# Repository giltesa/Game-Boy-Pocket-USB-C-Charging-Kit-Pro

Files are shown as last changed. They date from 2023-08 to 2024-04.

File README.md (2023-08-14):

# Game Boy Pocket USB-C Charging Kit PRO

The **Game Boy Pocket USB-C Charging Kit PRO** is the new circuit for **Nintendo Game Boy Pocket**. This time is all in one circuit and includes not only the **charging controller** but also a **boost converter** and **audio amplifier**.

The modern **IPS displays** with background light require more energy than the stock display. Also, **the flash cards** to load tons of games consume the battery very fast. If you really want to enjoy the games, the best way to do it is using a rechargeable battery instead of AA batteries.

However, that is not enough because a higher consume is forcing the original electronic to strive more than it can. That may cause noise in the speaker or headphones.

Typical solution has been adding a charging circuit for the battery and a power converter to replace the old and not efficiently one which is included in the GBP. Some people also add an audio amplifier to hear better the speaker sound. All these things make the GBP perfect, however the installation require a lot of cables and can not be easy for some people without enough knowledge.

Typical installation of the 3 modules:

GBC
*(Thanks Sascha for the photo of his GB **COLOR** installation!)*

For resolving that, this new **Game Boy Pocket USB-C Charging Kit PRO** includes the three circuits in one, everything wired each other, and you will just need to solder a few points to the GBP board.

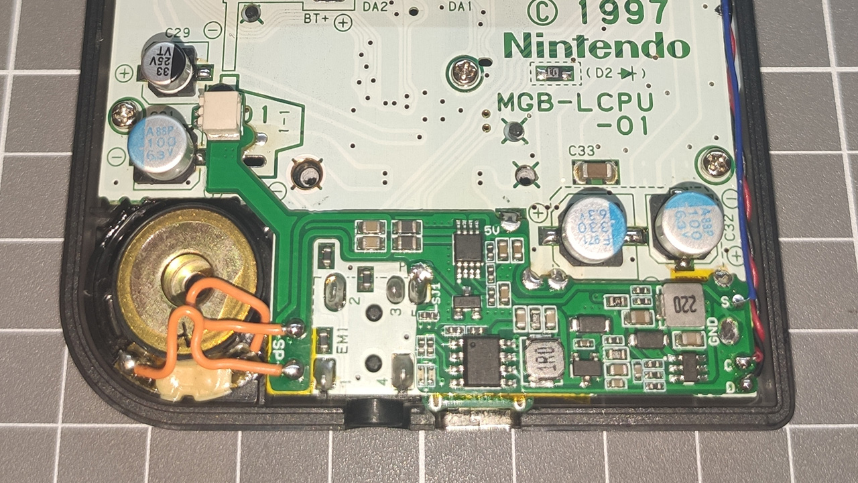
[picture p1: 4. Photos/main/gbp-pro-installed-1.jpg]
GBP


## FEATURES

-   Exact shape for Game Boy Pocket.
-   Li-Ion battery charger by USB-C with protection for charging level and overdischarge.
-   DC to DC converter (only 5V output, not compatible with the original display).
-   Audio amplifier for the speaker with a potentiometer called VR1 to setup the maximum volume.
-   Integrated LED indicators on the main board, next to the USB for charging battery (red) and full battery (green). It can be disabled by the jumper SJ1.
-   External LED indicators board for playing (white), charging battery (red) and full battery (green). Optional installation.

## Would you like it?

https://shop.giltesa.com/product/game-boy-pocket-usb-c-charging-kit-pro/

## More

- [giltesa.com](https://giltesa.com "giltesa.com")
- [twitter.com](https://twitter.com/giltesa "twitter.com")

## License

This project is licensed under a **Creative Commons** license:
**[Attribution-NonCommercial-ShareAlike 4.0 International (CC BY-NC-SA 4.0) ](https://creativecommons.org/licenses/by-nc-sa/4.0/)**

Check the [LICENSE.md](LICENSE.md) for more information.

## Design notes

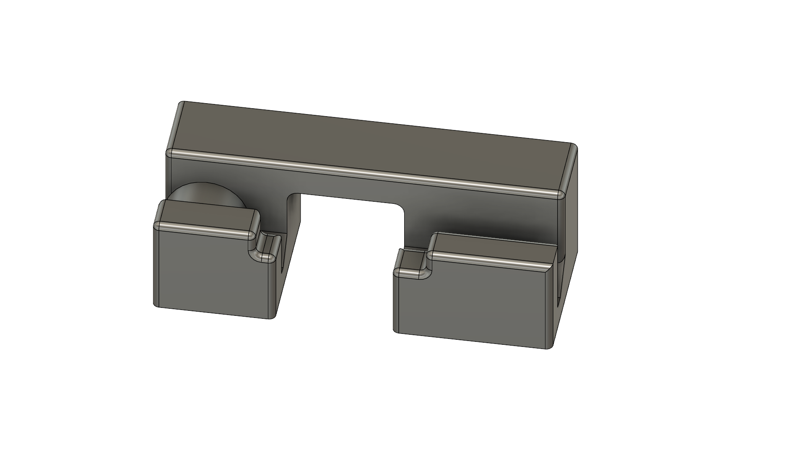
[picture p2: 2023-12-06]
2. Renders, 3D models/Cutting Tool/GBP - Cutting Tool v15.png

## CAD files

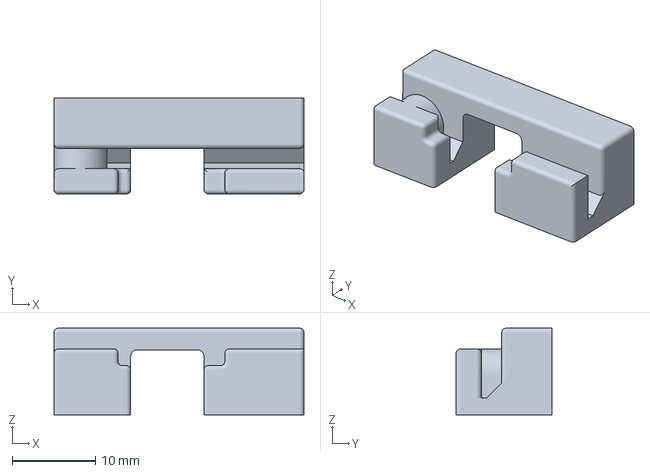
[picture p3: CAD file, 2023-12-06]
2. Renders, 3D models/Cutting Tool/GBP - Cutting Tool v15.3mf
30.0 x 11.5 x 10.4 mm

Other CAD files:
2. Renders, 3D models/Cutting Tool/GBP - Cutting Tool v15.f3d
2. Renders, 3D models/Cutting Tool/GBP - Cutting Tool v15.stl
2. Renders, 3D models/GBP USB-C Charging Kit Pro v3.1.skp

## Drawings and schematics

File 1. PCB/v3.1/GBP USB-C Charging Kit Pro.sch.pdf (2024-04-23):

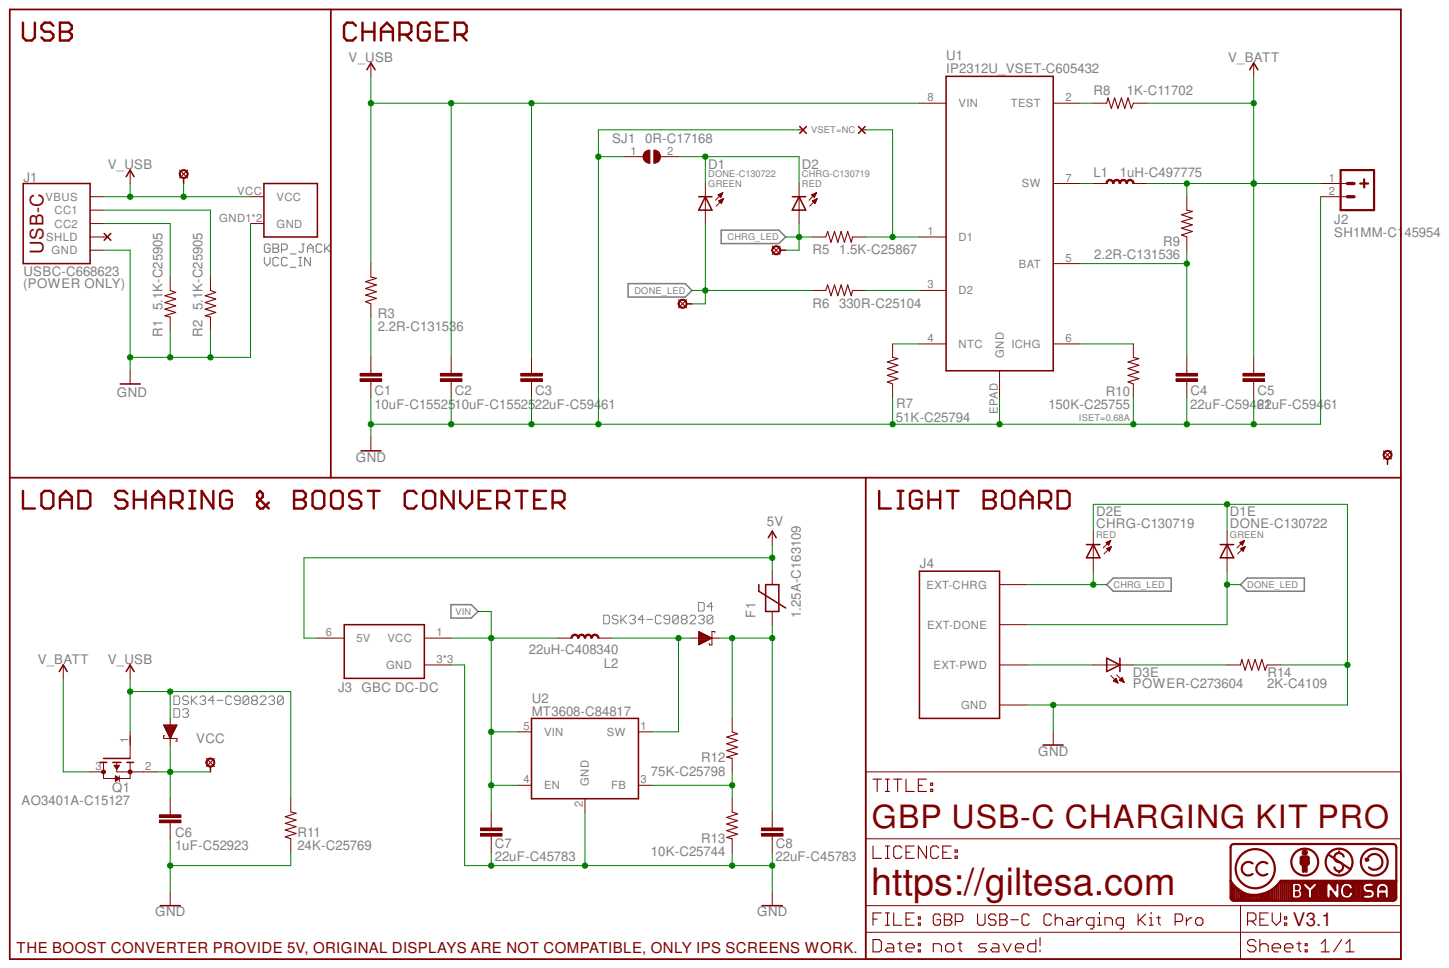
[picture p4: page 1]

GBP USB-C CHARGING KIT PRO
https://giltesa.com

THE BOOST CONVERTER PROVIDE 5V, ORIGINAL DISPLAYS ARE NOT COMPATIBLE, ONLY IPS SCREENS WORK.

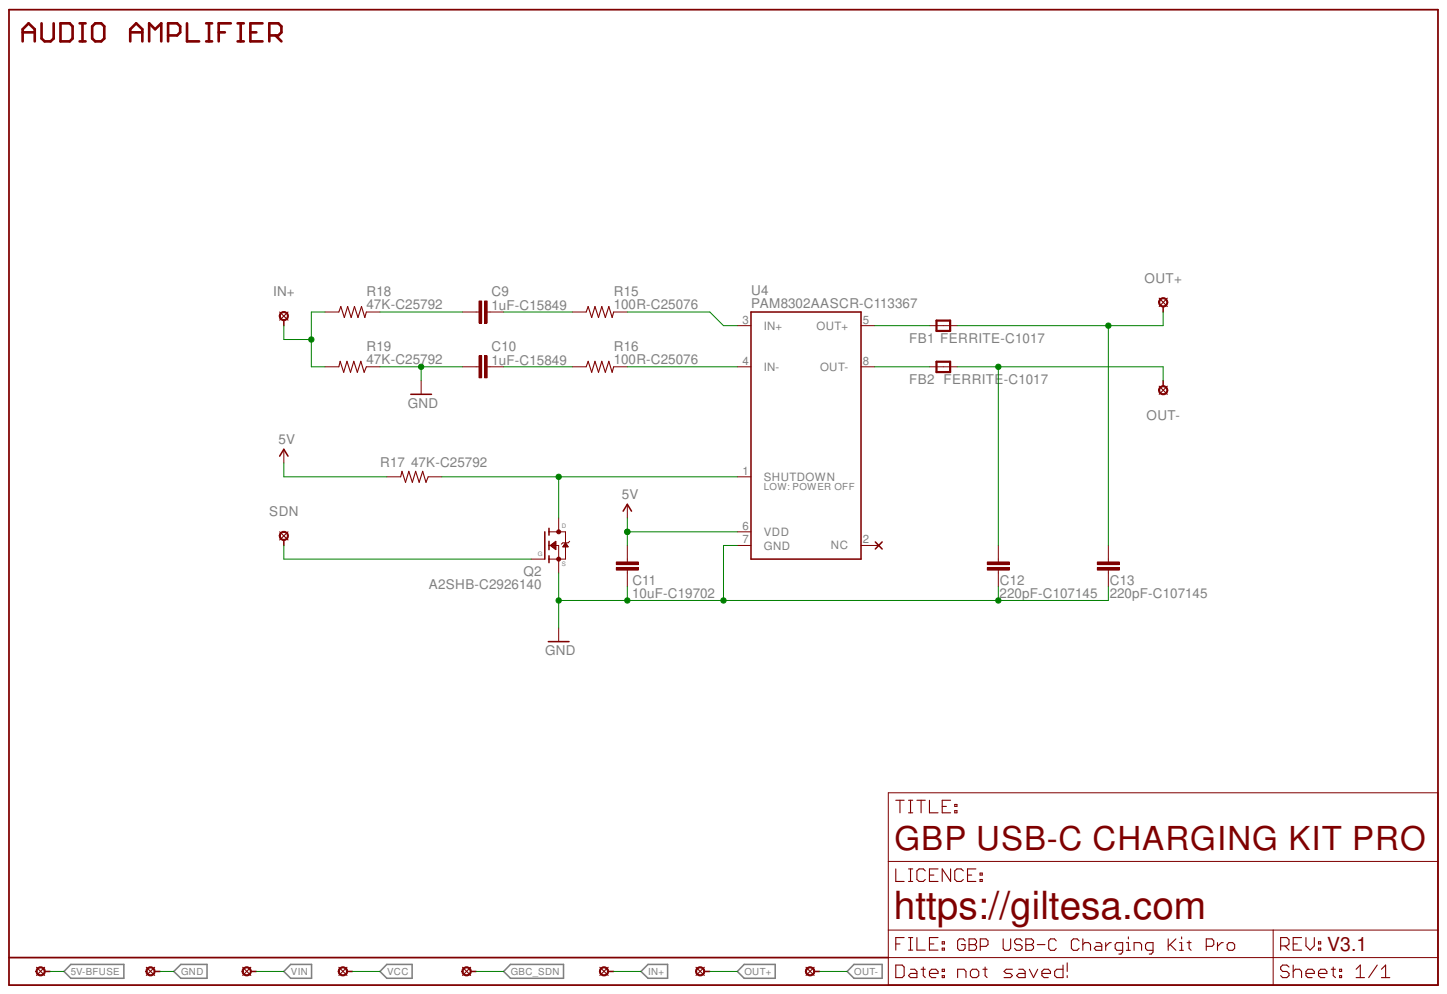
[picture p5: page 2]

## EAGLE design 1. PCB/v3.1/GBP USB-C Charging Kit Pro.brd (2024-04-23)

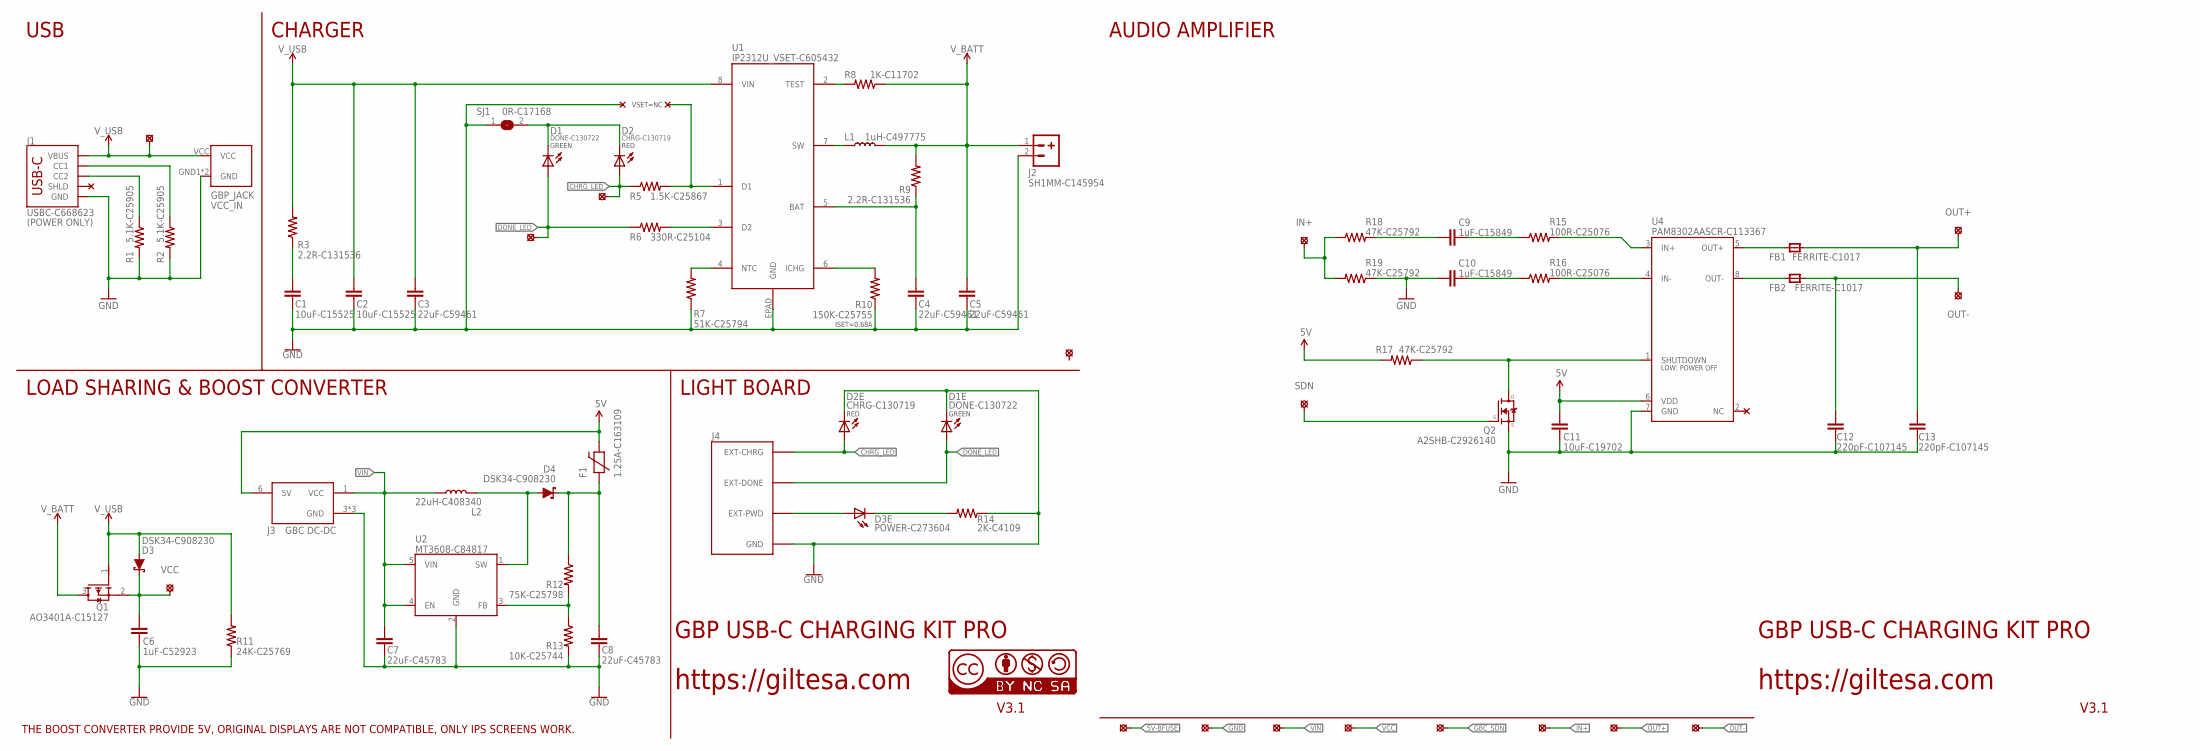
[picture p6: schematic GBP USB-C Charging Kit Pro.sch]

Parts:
C1, C2: 10uF-C15525; C0402_S
C3, C4, C5: 22uF-C59461; C0603_S
C6: 1uF-C52923; C0402_S
C7, C8: 22uF-C45783; C0805_S
C9, C10: 1uF-C15849; C0603_S
C11: 10uF-C19702; C0603_S
C12, C13: 220pF-C107145; C0805_S
D1, D1E: DONE-C130722; L0402
D2, D2E: CHRG-C130719; L0402
D3, D4: DSK34-C908230; SOD-123FL
D3E: POWER-C273604; L0402
F1: 1.25A-C163109; F0603_S
FB1, FB2: FERRITE-C1017; MICROBUILDER__0805MP_S
GBP_JACK: VCC_IN; GBP_POWER_JACK_DIP
J1: USBC-C668623; USB-C_6P
J2: SH1MM-C145954; JST-2-1MM-SMD_RIGHT
J3: GBC DC-DC; GBP_DC_DC_DIP_V2
J4: GBP_LED_V2
L1: 1uH-C497775; PSPMAA0402
L2: 22uH-C408340; PSPMAA0402
PP1, PP2, PP3, PP4, PP5, PP6, PP7, PP8: SOLDER_PAD-1.5; SOLDER_PAD_1.5
Q1: AO3401A-C15127; SOT23-3_S
Q2: A2SHB-C2926140; SOT23-3_S
R1, R2: 5.1K-C25905; R0402
R3, R9: 2.2R-C131536; R0402
R5: 1.5K-C25867; R0402
R6: 330R-C25104; R0402
R7: 51K-C25794; R0402
R8: 1K-C11702; R0402
R10: 150K-C25755; R0402
R11: 24K-C25769; R0402
R12: 75K-C25798; R0402
R13: 10K-C25744; R0402
R14: 2K-C4109; R0402
R15, R16: 100R-C25076; R0402
R17, R18, R19: 47K-C25792; R0402
SJ1: 0R-C17168; JUMPER-SMD_0402
U1: IP2312U_VSET-C605432; IP2312
U2: MT3608-C84817; SOT-23-6
U4: PAM8302AASCR-C113367; PAM8302AASCR
U$1: VCC; PAD_1.4
U$2: SDN; PAD_1.25
U$6: CC-BY-NC-SA15MM; CC-BY-NC-SA_15MM
U$20: OUT+; SOLDER_PAD_2.0
U$23: OUT-; SOLDER_PAD_2.0
U$24: CHRG_LED; SOLDER_PAD_1.3
U$25: DONE_LED; SOLDER_PAD_1.3
U$30: IN+; SOLDER_PAD_1.3
U$54: PAD_1.4
U$55: SOLDER_PAD-2.0; SOLDER_PAD_2.0

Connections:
5V: C11.1, F1.2, J3.6 (5V), R17.2, U4.6 (VDD)
5V-BFUSE: C8.2, D4.C, F1.1, PP1.P$1, R12.1
CHRG_LED: D2.A, D2E.A, J4.EXT-CHRG, R5.1, U$24.P$1
DONE_LED: D1.A, D1E.A, J4.EXT-DONE, R6.1, U$25.P$1
GBC_SDN: PP5.P$1, Q2.1 (G), U$2.P$1
GND: C1.1, C2.1, C3.1, C4.1, C5.1, C6.2, C7.1, C8.1, C10.2, C11.2, C12.2, C13.2, D1E.C, D2E.C, GBP_JACK.GND1 (GND), GBP_JACK.GND2 (GND), J1.A12-GND (GND), J1.B12-GND (GND), J2.2, J3.3 (GND), J3.3_1 (GND), J3.3_2 (GND), J4.GND, PP2.P$1, Q2.2 (S), R1.2, R2.2, R7.1, R10.1, R11.1, R13.2, R14.1, R19.1, SJ1.1, U1.EPAD (GND), U2.2 (GND), U4.7 (GND)
IN+: PP6.P$1, R18.1, R19.2, U$30.P$1
unnamed: D1.C, D2.C, SJ1.2
unnamed: D4.A, L2.P$2 (2), U2.1 (SW)
unnamed: J1.B5 (CC2), R1.1
unnamed: R8.2, U1.2 (TEST)
unnamed: R12.2, R13.1, U2.3 (FB)
unnamed: R16.2, U4.4 (IN-)
unnamed: D3E.A, J4.EXT-PWD, J4.EXT-PWD' (EXT-PWD)
unnamed: D3E.C, R14.2
unnamed: R15.2, U4.3 (IN+)
unnamed: J1.A5 (CC1), R2.1
unnamed: C4.2, R9.1, U1.5 (BAT)
unnamed: C1.2, R3.1
unnamed: C10.1, R16.1
unnamed: FB2.1, U4.8 (OUT-)
unnamed: R5.2, U1.1 (D1)
unnamed: FB1.1, U4.5 (OUT+)
unnamed: C9.1, R15.1
unnamed: C9.2, R18.2
unnamed: R7.2, U1.4 (NTC)
unnamed: R10.2, U1.6 (ICHG)
unnamed: R6.2, U1.3 (D2)
unnamed: L1.P$1 (1), U1.7 (SW)
OUT+: C13.1, FB1.2, PP7.P$1, U$20.P$1
OUT-: C12.1, FB2.2, PP8.P$1, U$23.P$1
SDN: Q2.3 (D), R17.1, U4.1 (SHUTDOWN)
VCC: C6.1, D3.C, PP4.P$1, Q1.2 (S), U$1.P$1
VIN: C7.2, J3.1 (VCC), L2.P$1 (1), PP3.P$1, U2.4 (EN), U2.5 (VIN)
V_BATT: C5.2, J2.1, L1.P$2 (2), Q1.3 (D), R8.1, R9.2
V_USB: C2.2, C3.2, D3.A, GBP_JACK.VCC, J1.A9-VBUS (VBUS), J1.B9-VBUS (VBUS), Q1.1 (G), R3.2, R11.2, U1.8 (VIN), U$54.P$1

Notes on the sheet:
GBP USB-C CHARGING KIT PRO
https://giltesa.com
V3.1
(POWER ONLY)
THE BOOST CONVERTER PROVIDE 5V, ORIGINAL DISPLAYS ARE NOT COMPATIBLE, ONLY IPS SCREENS WORK.
USB
CHARGER
LOAD SHARING & BOOST CONVERTER
AUDIO AMPLIFIER
LIGHT BOARD
ISET=0.68A
GREEN
RED
VSET=NC

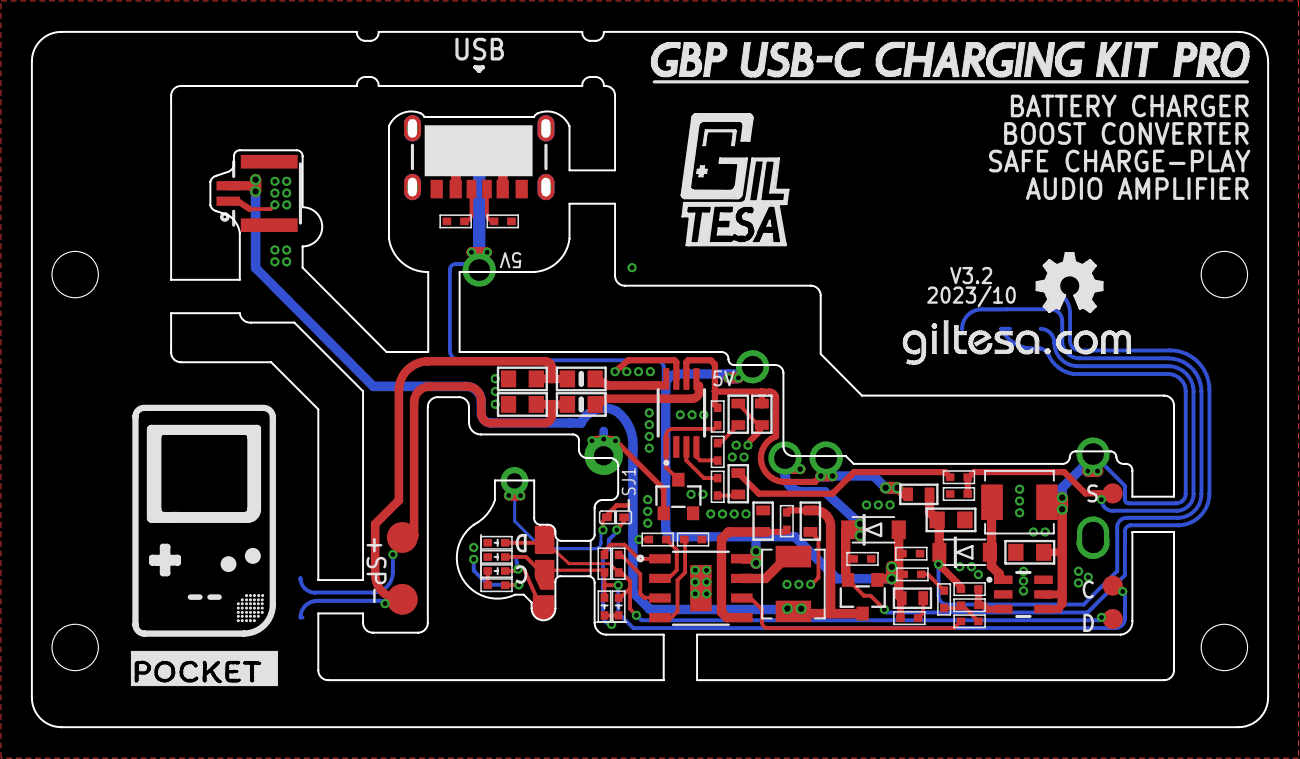
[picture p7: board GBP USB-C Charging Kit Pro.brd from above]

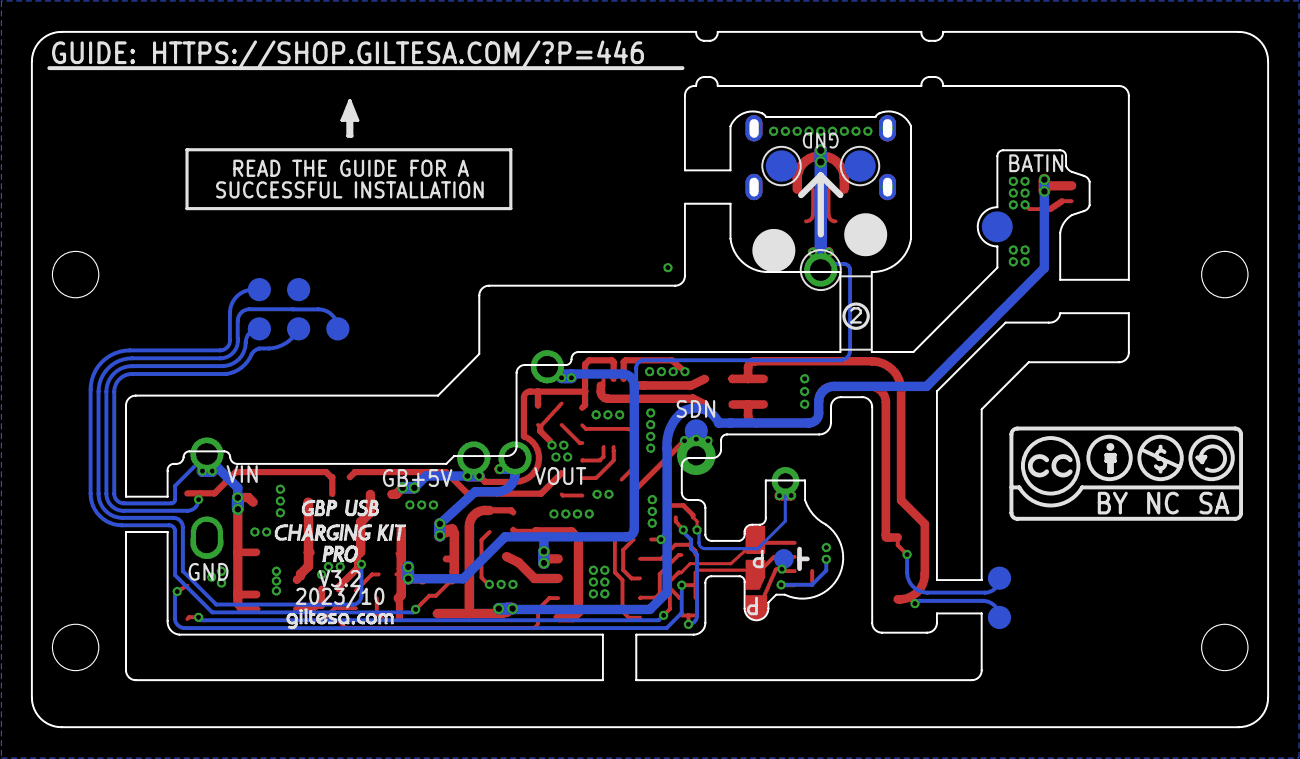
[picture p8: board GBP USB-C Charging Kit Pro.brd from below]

Board: 2 copper layers, 80.0 x 45.0 mm, 80 parts (13 on the bottom side), 36 nets.

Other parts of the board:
LOGO1: OSHW_LOGO_FILLX0150-NT; OSHW_FILLX150_NOTEXT
U$3: GILTESA_LOGO_MASK_9MM
U$4: GBP_PRO_FRAME
U$7: GILTESA.COM_MASK
U$31: GBP_FRAME_LOGO
U$34: GAME_BOY_POCKET_USB_CHARGING_KIT_PRO
U$52: GILTESA.COM_MASK_7MM
U$61: SCISSOR_TWO

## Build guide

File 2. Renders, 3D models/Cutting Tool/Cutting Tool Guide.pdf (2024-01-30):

# Cutting tool for GAME BOY POCKET

PRODUCT

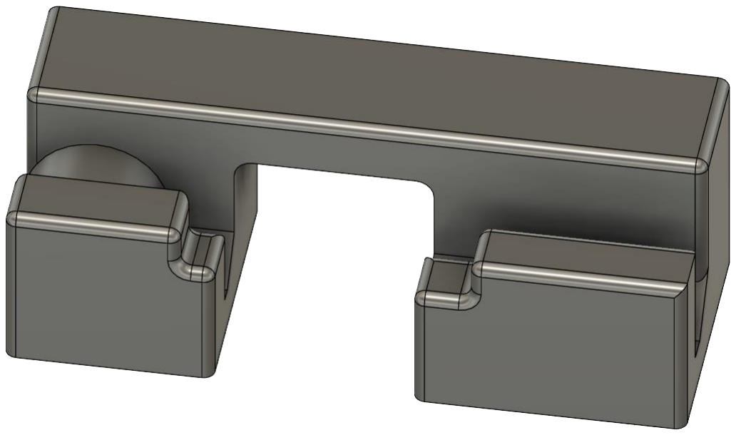
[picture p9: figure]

https://shop.giltesa.com/product/game-boy-pocket-usb-c-cutting-tool

# Description

This plastic tool made by 3D printer will help you to make a perfect hole on your Game Boy Pocket shell. It works as a template which helps to drill the hole in the exactly place where it needs to be.

# REQUIRED (NOT INCLUDED)

- Permanent marker (https://www.aliexpress.com/w/wholesale-black-permanent-Marker-0.5mm.html)
- Cutter (https://www.aliexpress.com/wholesale?SearchText=Cutter+scalpel)
- Rotary tool like a Dremel with drill bits or diamond burs for cutting the hole.

# Instructions

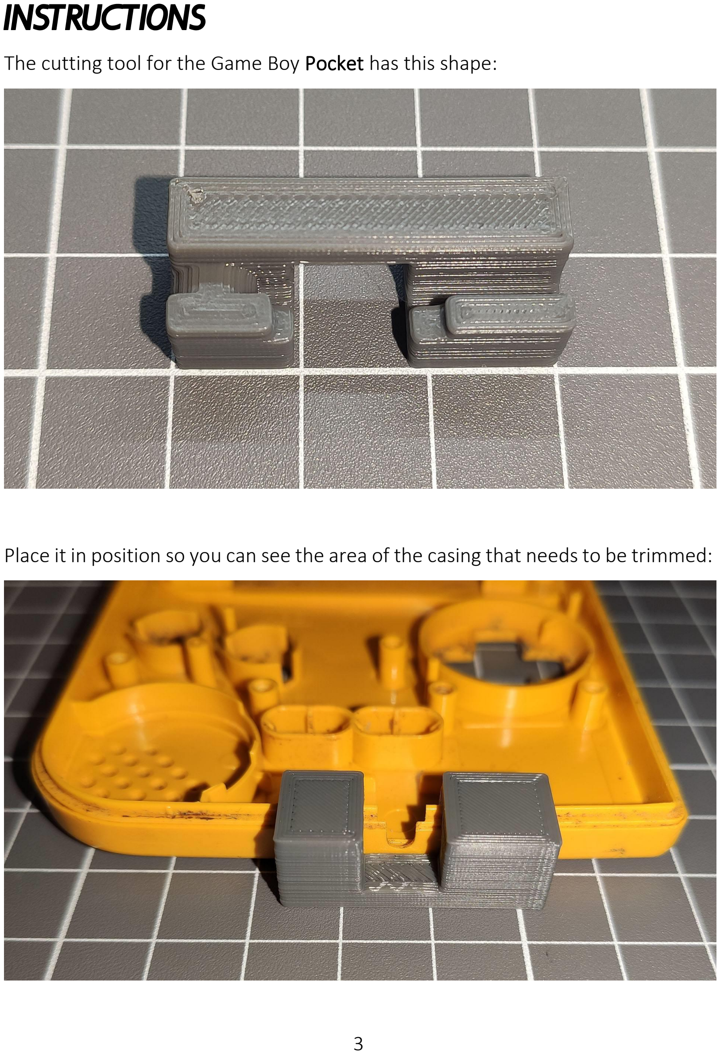
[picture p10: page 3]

The cutting tool for the Game Boy Pocket has this shape:

Place it in position so you can see the area of the casing that needs to be trimmed:

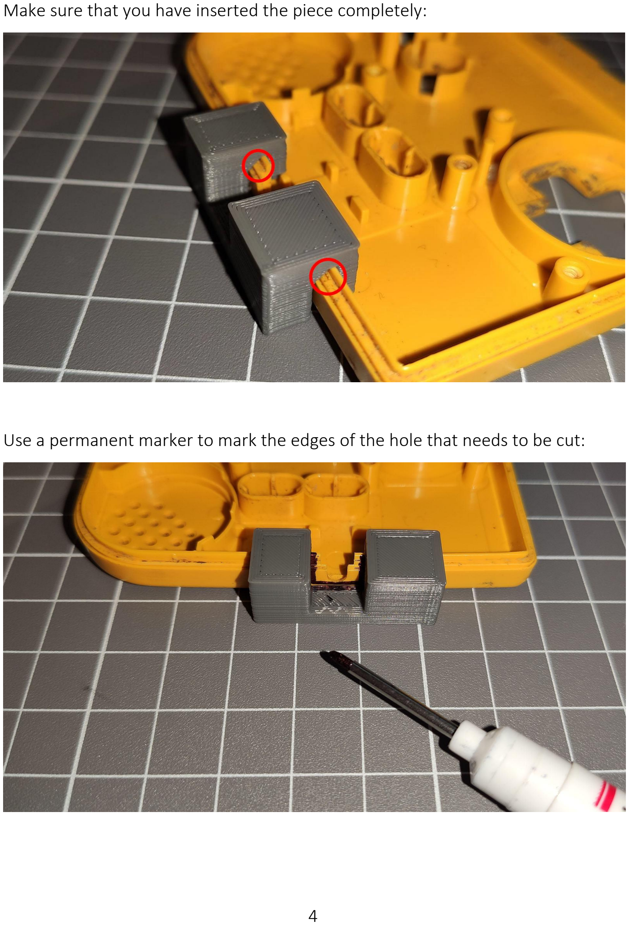
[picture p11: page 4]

Make sure that you have inserted the piece completely:

Use a permanent marker to mark the edges of the hole that needs to be cut:

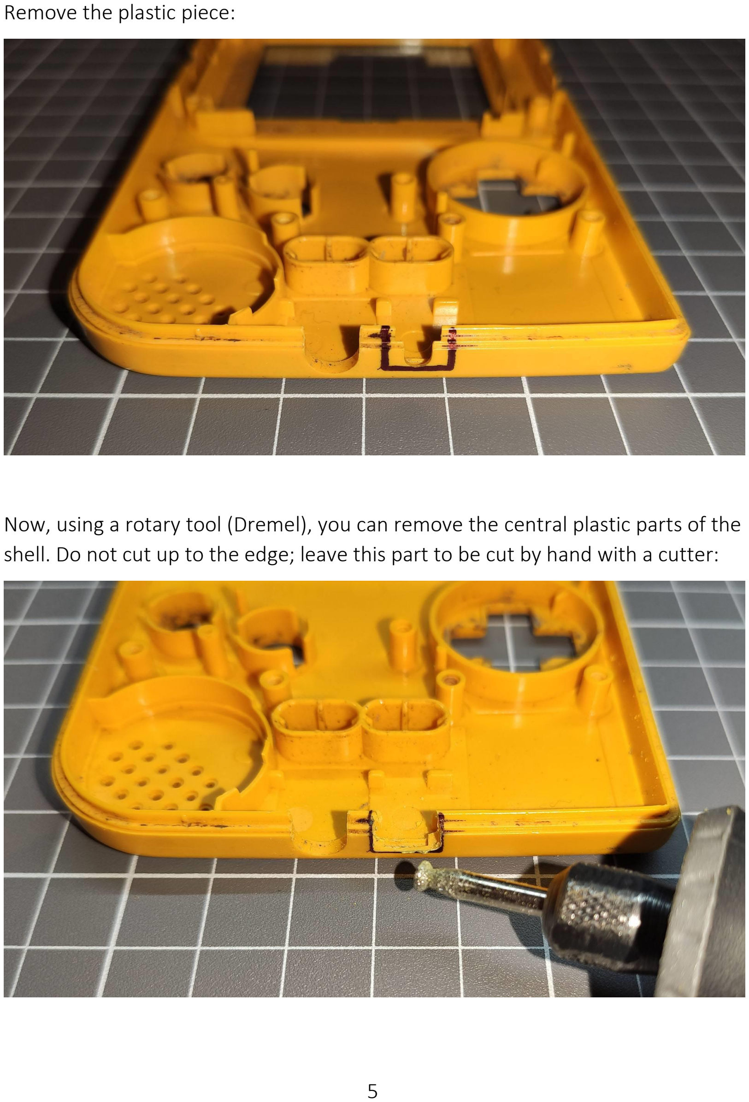
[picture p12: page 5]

Remove the plastic piece:

Now, using a rotary tool (Dremel), you can remove the central plastic parts of the shell. Do not cut up to the edge; leave this part to be cut by hand with a cutter:

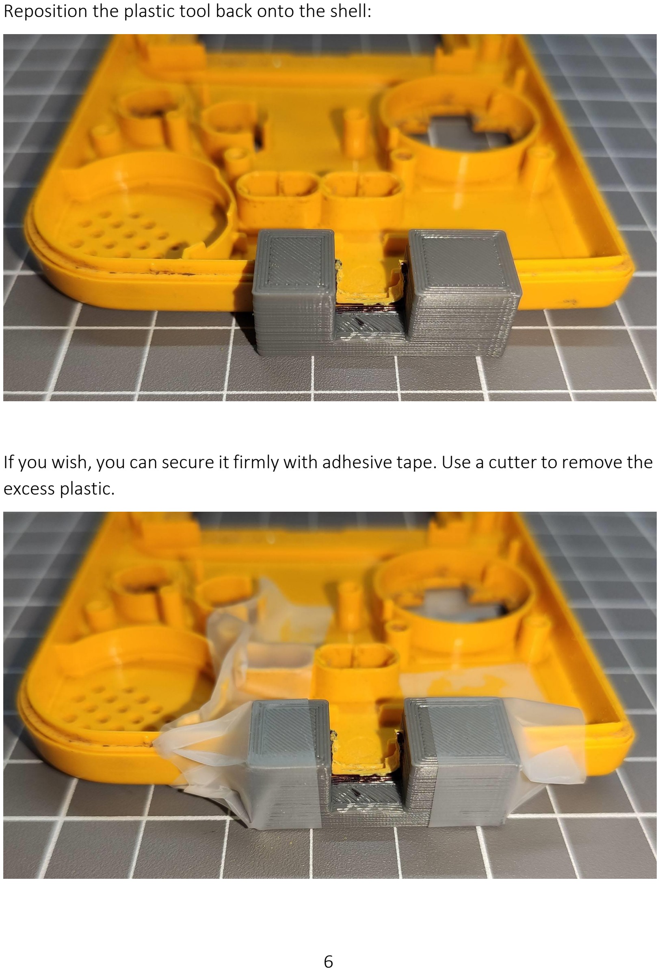
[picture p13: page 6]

Reposition the plastic tool back onto the shell:

If you wish, you can secure it firmly with adhesive tape. Use a cutter to remove the excess plastic.

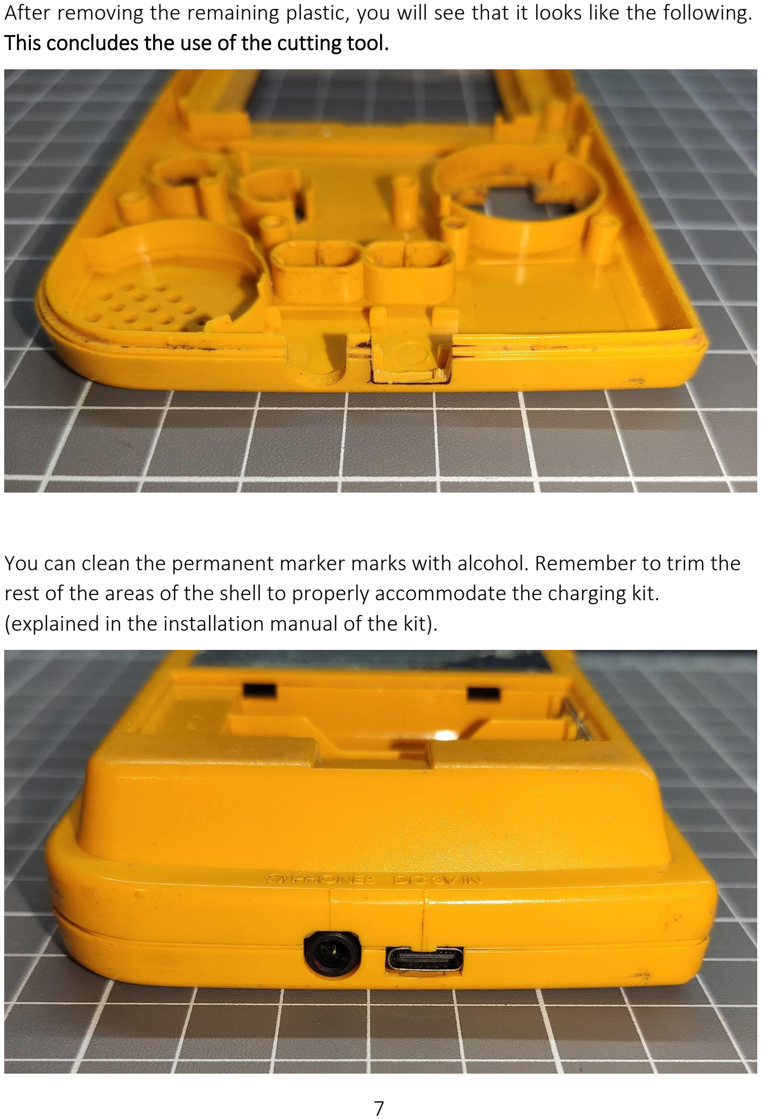
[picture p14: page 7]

After removing the remaining plastic, you will see that it looks like the following. This concludes the use of the cutting tool.

You can clean the permanent marker marks with alcohol. Remember to trim the rest of the areas of the shell to properly accommodate the charging kit. (explained in the installation manual of the kit).

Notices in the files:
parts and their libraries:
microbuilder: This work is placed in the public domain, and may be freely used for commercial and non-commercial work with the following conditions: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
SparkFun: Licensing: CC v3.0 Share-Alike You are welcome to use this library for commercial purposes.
